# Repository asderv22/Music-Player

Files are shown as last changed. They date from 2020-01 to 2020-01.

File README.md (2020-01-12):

# 普通的播放器   Music-Player in a remote's case
这是一个在格力空调遥控器外壳里的播放器
----
This is a music player in a aircon remote's case
----
Engish vision in part 2
----
<br>

可实现功能
----
实现一个播放器该有的功能 <br>
解码mp3 flac wav <br>
支持存储卡和蓝牙播放 <br>
~~以及锤子母公司没有提供的耳机插孔~~  <br>
<br>

使用材料
----
定制PCB x1 **提供lceda源码和.pcb文件 在files/pcb** <br>
电子元件 xn **详情参见bom表 在files/bom** <br>
TF卡 x1 （可选） <br>
耳机或者脑放 x1 <br>
格力原装空调遥控器 x1 型号YBF02 <br>
格力仿冒遥控器 x1 （可选） **要这个是为了取屏幕 原装的mcu部件打到电池位置了 单独割掉屏幕不工作** <br>
<br>

关于文件的重要解释
----
显示屏控制代码适用8051单片机 在files/screen <br>
电路原理图在files里 展示为pdf文件 <br> 
原理图通过lceda绘制 .json文件是lceda源码 <br> 
**提供altiumdesigner文件 但不保证完整性与正确性** <br>
<br>
pcb源码展示为files/pcb/player.json<br>
可导入lceda编辑 <br>
**pcb制造Gerber文件展示在files/pcb/Gerber_player.zip** <br>
**使用lceda绘制 生产前请使用Gerber浏览器检查要求** <br>
**提供alitumdesigner文件 由lceda导出 展示为files/pcb/player.pcbdoc** <br>
**由于是导出文件 不确保准确性与可用性 具体参考lceda对于导出文件的解释** <br>
https://docs.lceda.cn/cn/Export/Export-Altium/index.html <br>
<br>

# English vision
Functions
----
as its described, this is a music player in a aircon remote's case <br>
It has all the functions that a music player should have <br>
including decode mp3 flac wav files <br>
buletooth and a sd slot <br>
~~and a headphone jack which apple doesn't have~~ <br>
<br>

Materials used
----
custom PCB x1 **the lceda sourcecode and altium's .pcb files are provided, in flies/pcb** <br>
lots of electronic components **see the bom list for detail, in files/bom**  <br>
TFcard x1 (optional)  <br>
original GREE YBF02  x1 
third-party GREE remote x1 (optional) **this is used to takeout its screen since the stock screen won't work if being cut off**  <br>
<br>

Important explainations of the files
----
the code of controlling the screen works on 8051 mcu ,it's in files/screen <br>
the circuit diagrams are shown as .pdf files in the\files folder <br>
diagrams are drew using LCEDA **also known as easyeda worldwide** <br>
the .json files are LCEDA source codes which allows import and reedit <br>
<br>

the PCB is created via lceda<br>
sourcecodes are shown as files/pcb/keyboard.json <br>
also allows import and reedit <br>
**PCB Gerber files are shown as files/pcb/Gerber_player** <br>
**its created via lceda， please check with Gerber broswer before production**<br>
**Alitumdesigner files are provided, shown as files/pcb/player.pcbdoc**  <br>
**Alitumdesigner files are provided, shown as files/pcb/keyboard.pcbdoc**<br>
**but they are exported by lceda,so the accuracy is unknown** <br>
**for more information,see the link below about lceda's exported files**<br>
https://docs.lceda.cn/en/Export/Export-Altium/index.html<br>

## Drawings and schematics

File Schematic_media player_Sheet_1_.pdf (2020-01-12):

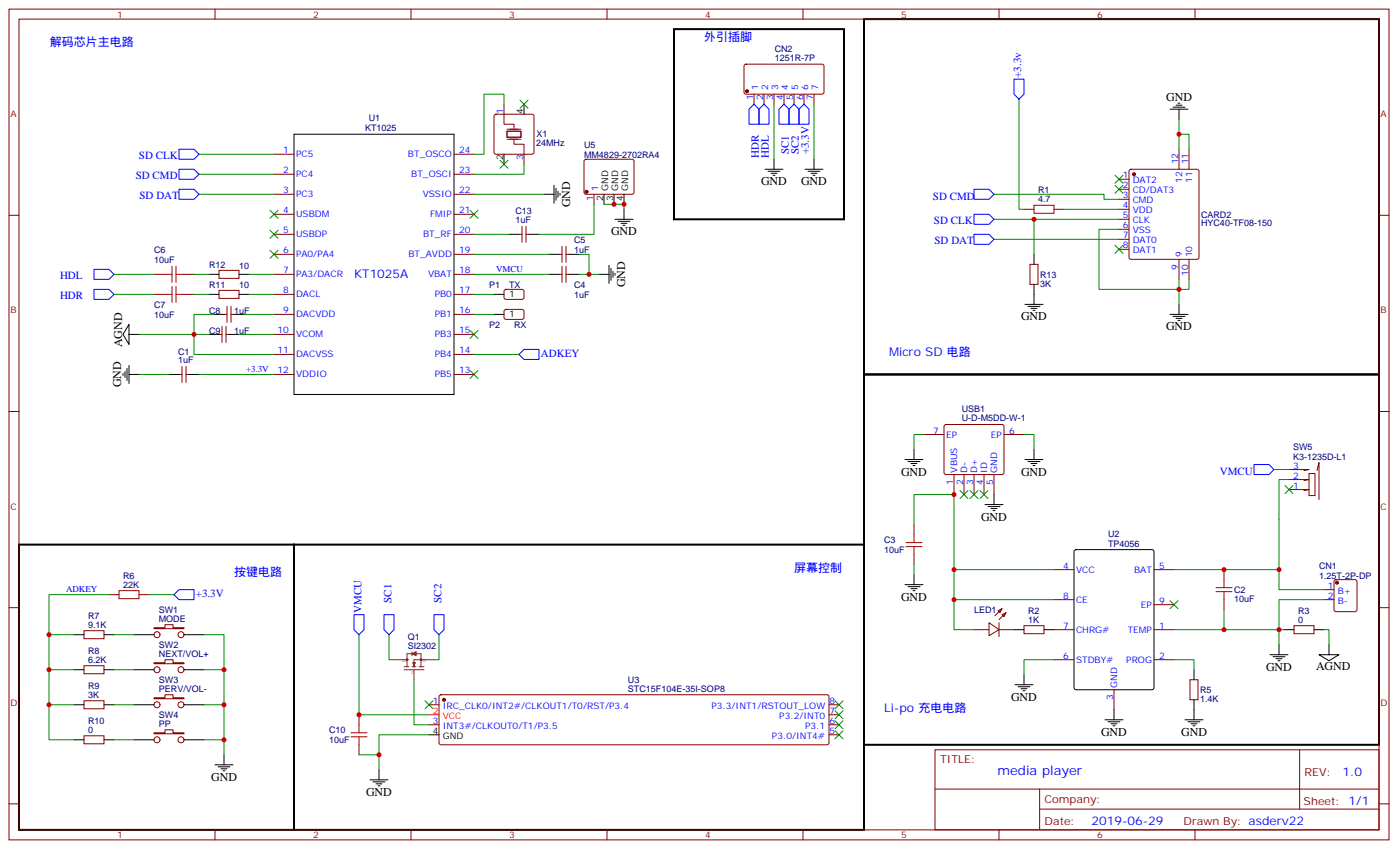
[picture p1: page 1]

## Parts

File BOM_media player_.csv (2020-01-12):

ID | Name | Designator | Footprint | Quantity | Manufacturer Part | Manufacturer | Supplier | Supplier Part | LCSC Assembly
1 | KT1025A | U1 | QSOP-24_24PIN-L8.2-W6.0-H1.72-PITCH0.635-BL | 1 | KT1025A | 清月电子
2 | TP4056 | U2 | SOP-8_150MIL | 1 | TP4056 | TOPPOWER | LCSC | C16581 | Yes
3 | 10 | R12,R11 | 0805' | 2 | RS-05K100JT | FH | LCSC | C131388
4 | 24MHz | X1 | OSC-YSX-3225_4P | 1 | X322524MMB4SI | YXC | LCSC | C70583 | Yes
5 | 1uF | C1,C5,C4,C9,C8,C13 | 0805' | 6 | CC0805ZRY5V8BB105 | YAGEO | LCSC | C106837
6 | 10uF | C3,C2,C10,C6,C7 | 0805' | 5 | 0805F106Z100 | WTC | LCSC | C83061
7 | K3-1235D-L1 | SW5 | SW-DIP-9X3.5-3.5-3P | 1 | K3-1235D-L1 | Rectangular Connectors - Contacts | LCSC | C223840
8 | HYC40-TF08-150 | CARD2 | TF-002-H18 | 1 | HYC40-TF08-150 | 华宇创 | LCSC | C341096
9 | 1K | R2 | 0603' | 1 | 0603WAJ0102T5E | UniOhm | LCSC | C25585
10 | 1.4K | R5 | 0805' | 1 | 0805W8F1401T5E | UniOhm | LCSC | C17388 | Yes
11 | STC15F104E-35I-SOP8 | U3 | SOP-8_150MIL | 1 | STC15F104E-35I-SOP8 | STC | LCSC | C106847
12 | 0 | R3,R10 | 0805' | 2 | 0805W8F9101T5E | UniOhm | LCSC | C17855 | Yes
13 | 9.1K | R7 | 0805' | 1 | 0805W8F0000T5E | UniOhm | LCSC | C17477 | Yes
14 | 4.7 | R1 | R0805 | 1 | RS-05L4R70FT | Guangdong Fenghua Advanced Tech | LCSC | C139875
15 | 22K | R6 | 0805' | 1 | RS-05K2202FT | Guangdong Fenghua Advanced Tech | LCSC | C304826
16 | 1251R-7P | CN2 | 1.25T-1-7AW | 1 | 1251R-7P | Shenzhen Cankemeng | LCSC | C220114
17 | 1.25T-2P-DP | CN1 | 1.25T-2P-DP | 1 | 1.25T-2P-DP | HRO | LCSC | C145940
18 | 3K | R9,R13 | 0805' | 2 | RS-05K3001FT | FH | LCSC | C136600
19 | 6.2K | R8 | 0805' | 1 | RS-05K6201FT | FH | LCSC | C139855
20 | SI2302 | Q1 | SOT-23(SOT-23-3) | 1 | SI2302 | Hottech | LCSC | C181087 | Yes
21 | U-D-M5DD-W-1 | USB1 | MICRO-USB-A14 | 1 | U-D-M5DD-W-1 | HRO | LCSC | C145795
22 | MM4829-2702RA4 | U5 | MM4829-2702RA4 | 1 | MM4829-2702RA4 | Murata Electronics | LCSC | C167502
23 | TJ-L3FYTGHRMFCLFLC2R-A5 | LED1 | LED-DIP-3.9MM | 1 | TJ-L3FYTGHRMFCLFLC2R-A5 | TOGIALED | LCSC | C330774
